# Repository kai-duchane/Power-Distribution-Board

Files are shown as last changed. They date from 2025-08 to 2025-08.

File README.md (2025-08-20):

# Power-Distribution-Board
The repository for the custom power distribution board in the Avanti Office.

This project is a 16 port remote controlled individually addressable 600W dual power supply, used to power 12 nvidia jetson orin nanos and 3 nvidia orin AGX computers on the server rack in the office. The 2 8 way relays and ws2812b leds for each DC port is controlled by a luckfox rv1106 connected serially through a txs0108e level shifter to an arduino nano. This project uses python flask to incorporate a web remote so users can simply type in the IP of the rv1106 and control the system. To connect to the flask remote, type the IP address the luckfox is connected to in the search bar.

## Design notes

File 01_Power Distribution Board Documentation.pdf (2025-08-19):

### VERSION 1.0

### AUGUST 2025

# Power Distribution Board

### BY: KAI DUCHANE

AVANTI R&D

Confidential

### OVERVIEW

1.1-SYSTEM DESCRIPTION

This project implements a 1U dual 600W server power supply system, connected to 2 microcontrollers (Luck fox RV1106 Pico Pro/Max and Arduino Nano) to power 12 Nvidia Jetson Orin Nanos and 3 Nvidia Orin AGX computers. The system runs a python flask for remote control. The power is supplied through 16 DC jacks; each connected to an individually controlled relay channel which is also connected to a ws2812b LED for status indication.

1.2-PROJECT RESOURCES

GitHub Repository: https://github.com/kai-duchane/Power-Distribution-Board

Contains: Source code, 3D models, KiCAD Schematics

1.3-POWER SPECIFICATIONS

Total Power Capacity: 600W

Input Voltage: 100-240VAC

Output Voltage: 12V, 50A (max) on each channel

1.4-PHYSICAL SPECIFICATIONS

DIMENSIONS

Height: 1.7" (43mm) - Standard 1U form factor,

Width: 17.2" (437mm) - Standard 19" rack width

Depth: 19.98" (507mm)

1.5-CONTROL SPECIFICATIONS

Primary Controller: Luck fox RV1106 (relay control, web server)

Secondary Controller: Arduino Nano (LED control)

Communication: Serial UART between controllers through TXS0108e level shifter

Network Interface: Ethernet via RV1106

Status Indicators: 16x WS2812B addressable RGB LEDs

### OPERATING INSTRUCTIONS

2.1-INITIAL SETUP

1. Network Configuration
- Connect RV1106 to network via Ethernet cable
- SSH into RV1106 using root@[IP Address], password: luckfox
- Start flask code using: python3 psu.py
- Access web interface: http://[IP]
2.2-LED STATUS INDICATORS
LED Color | Status
Green | Channel ON - Normal
Red | Channel OFF
Blinking White | Startup/Transition

2.3-SAFETY PROCEDURES

1. Always disconnect power before servicing
2. Ensure proper grounding
3. Do not exceed rated loads

### HARDWARE COMPONENTS

3.1-KICAD SCHEMATIC

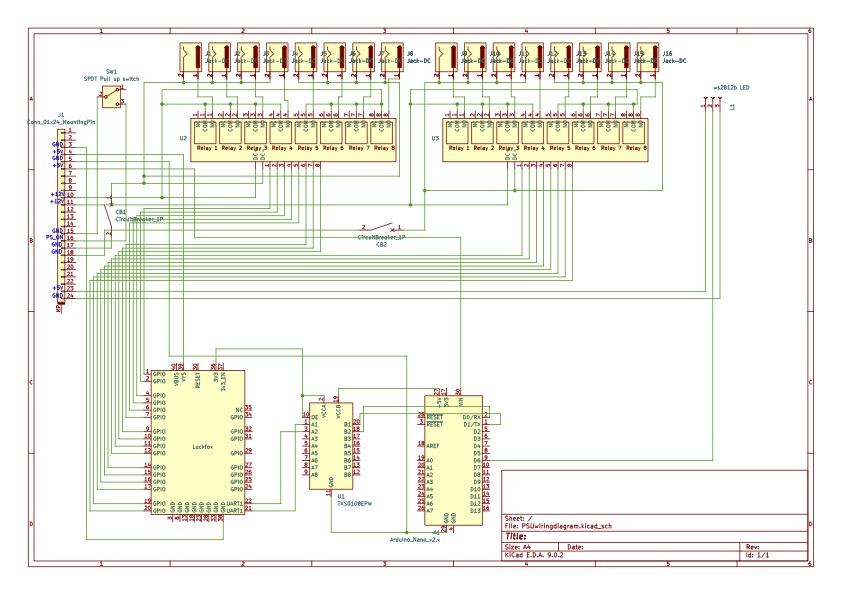
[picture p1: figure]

NOTES:
- Two 8-channel relay modules providing 16 total switching channels
- Both microcontrollers are powered by 5V and share common GND between them and level shifter
- UART RX to TX and TX to RX
- Pins 1 & 2 on RV1106 are reserved for debugging, connected to pins 25 and 26.

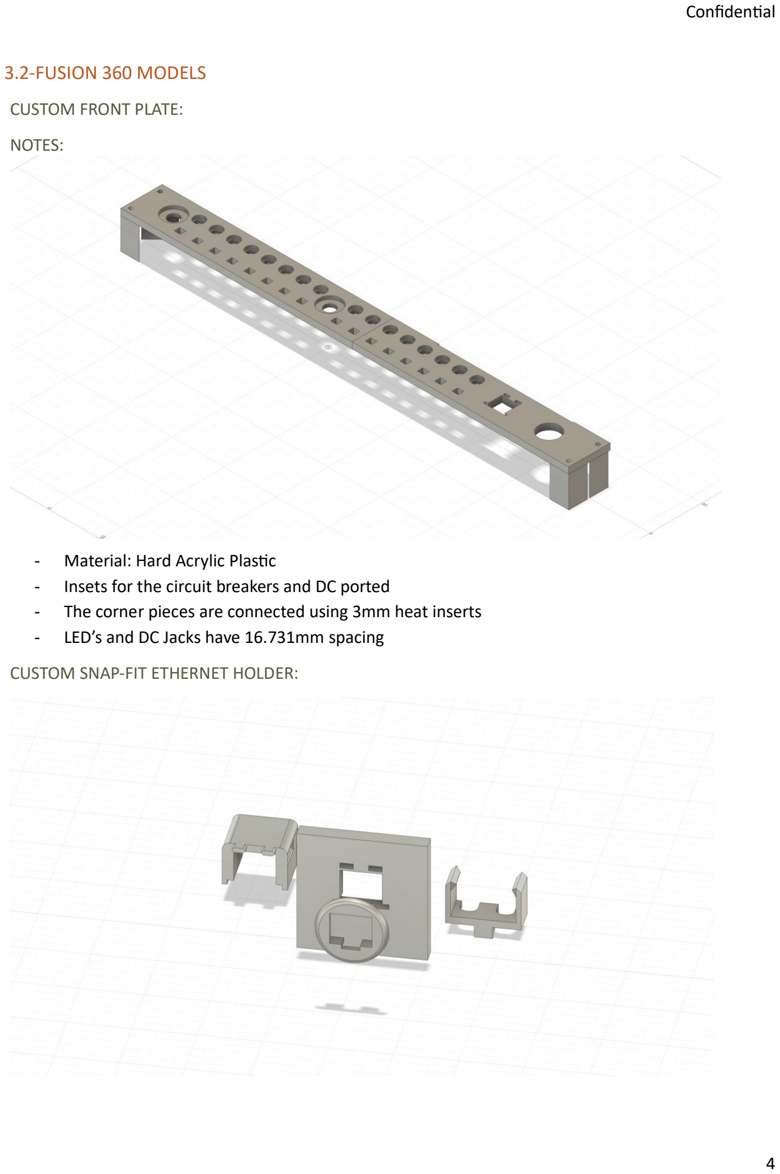
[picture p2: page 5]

3.2-FUSION 360 MODELS

CUSTOM FRONT PLATE:

NOTES:

- Material: Hard Acrylic Plastic
- Insets for the circuit breakers and DC ported
- The corner pieces are connected using 3mm heat inserts
- LED’s and DC Jacks have 16.731mm spacing

CUSTOM SNAP-FIT ETHERNET HOLDER:

NOTES:

- 3 components: Top Holder, Bottom Holder, and Cover Plate
- Top and bottom holders are snap-fit

3.3-CNC TOOLPATH

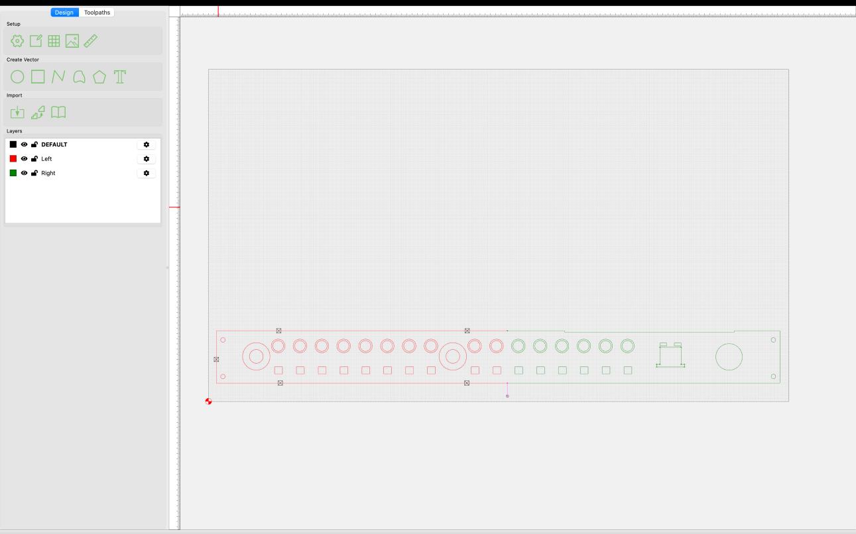
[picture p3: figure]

NOTES:

- Two toolpaths to slide board over and print
- Dimensions:
- Width: 444.500 mm
- Height: 254.000 mm
- Thickness: 6.100 mm

### SOFTWARE ARCHITECTURE

4.1-SYSTEM LOGIC FLOW

[Web UI Remote Control]

↓

[Flask Web Server on RV1106]

↓

[Relay Control Logic]

↓

[Serial Command to Arduino]

↓

[LED Status Update]

4.2-WEB INTERFACE FEATURES

Individual channel ON/OFF control

Status monitoring dashboard

Bulk Controls:

- ALL ON/OFF: Turns on/off all 16 outputs simultaneously
- Emergency Stop: Immediately cuts power to all outputs
- Test Sequence: Cycles through all outputs for testing

4.3-COMMUNICATION PROTOCOL

1. Web Browser ↔ Flask Server (HTTP/REST API)

Protocol: HTTP REST API over port 80

2. Flask Server ↔ Arduino (Serial UART)

Interface: UART1 (/dev/ttyS1)

Baud Rate: 9600 bps

Protocol: Simple character-based commands

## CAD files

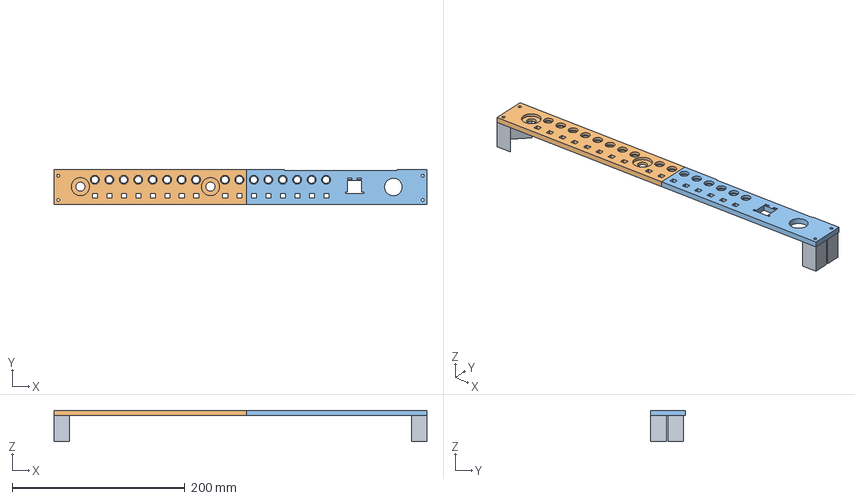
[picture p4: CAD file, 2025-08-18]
05_Power Distribution Board Front Plate Model.step
431.8 x 40.0 x 36.0 mm

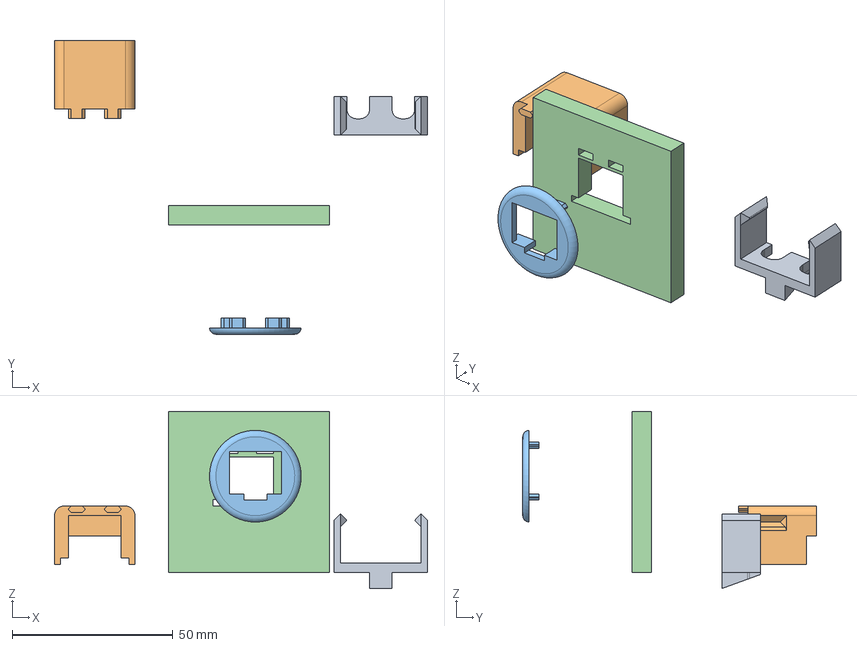
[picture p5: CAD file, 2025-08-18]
06_Snap-fit Microcontroller Holder Model.step
115.9 x 91.2 x 55.0 mm

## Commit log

2025-08-12 Create Arduino code for nano
2025-08-18 Update Arduino code for nano
2025-08-18 Create Luckfox pico code python
2025-08-19 Rename Power Distribution Board Documentation.pdf to 02_Power Distribution Board Documentation.pdf
2025-08-19 Rename Full-Distribution Board.kicad_sch to 03_Full-Distribution Board.kicad_sch
    [03_Full-Distribution Board.kicad_sch]
2025-08-19 Rename Luckfox pico code python to 04_Luckfox pico code python
2025-08-19 Rename Arduino code for nano to 05_Arduino code for nano
2025-08-19 Rename Power Distribution Board Front Plate Model.step to 06_Power Distribution Board Front Plate Model.step
    [06_Power Distribution Board Front Plate Model.step]
2025-08-19 Rename Snap-fit Microcontroller Holder Model.step to 07_Snap-fit Microcontroller Holder Model.step
    [07_Snap-fit Microcontroller Holder Model.step]
2025-08-20 Rename 02_Power Distribution Board Documentation.pdf to 01_Power Distribution Board Documentation.pdf
2025-08-20 Rename 03_Full-Distribution Board.kicad_sch to 02_Full-Distribution Board.kicad_sch
    [02_Full-Distribution Board.kicad_sch]
2025-08-20 Rename 04_Luckfox pico code python to 03_Luckfox pico code python
2025-08-20 Rename 06_Power Distribution Board Front Plate Model.step to 05_Power Distribution Board Front Plate Model.step
    [05_Power Distribution Board Front Plate Model.step]
2025-08-20 Rename 07_Snap-fit Microcontroller Holder Model.step to 06_Snap-fit Microcontroller Holder Model.step
    [06_Snap-fit Microcontroller Holder Model.step]
